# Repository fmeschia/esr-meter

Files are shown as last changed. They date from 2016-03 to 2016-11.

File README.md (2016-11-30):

ESR Meter
=========
An Arduino-based battery internal resistance meter.

Introduction
------------
This device measures the internal resistance of a battery by measuring the voltage difference at the battery terminals when a load is applied and then removed. By measuring the difference in voltage and the difference in current, the resistance is readily determined via Ohm's law.

Design goals
------------
* Measure internal resistance for batteries with voltages ranging from a 4-cell NiXX to a 4S LiPo pack
* Resistance range: 1 to 1000 mOhm
* Ability to do 4-wire measurements
* Target precision: 2% ± 1 LSB
* Ability to draw power either from the battery under test, or from a separate battery
* Powered by the Atmel ATMega328P microcontroller (so that it can be prototyped with Arduino)
* Low cost!

Design
------

This device measures the internal resistance by using Ohm's law: R = ∆V/∆I. The battery is first connected to a load, then the load is removed. The voltage at the battery teminals is measured just before removing the load, and just after the load is removed. The current drawn from the battery is also measured, almost simultaneously with the two voltage measurements.

Voltage and current measurement is performed using a 4-wire (Kelvin) technique: current is measured by a sensing resistor along the "hot" high-current path which connects the battery to the load, and voltage is sensed through two "cold" leads, that carry no current. This also allows for internal resistance measurement of the individual cells in a multi-cell battery, as long as the individual cell voltages are available at a balance tap.

One of the problems that must be solved is how to measure voltages (like the two battery under test terminals) which may exceed the ADC reference voltage. The ATMega328P microcontroller can be powered with 5.5V maximum, so if we were to do a direct measurement (battery terminals direct to ADC inputs) we would be only be able to measure a 4-cell NiXX battery... if it's not fully charged.

One possibility to overcome this problem would be to use differential analog amplifiers to bring the voltages within the measurement range. The gain and the baseline of the amplifiers could be adjusted by the micro with digital potentiometers, to adapt to different battery voltages. The drawback is the number of additional components, which influences the cost of the device.

Instead of going this route, we decided to use "AC coupling". The voltages sensed at the battery terminals are filtered through one-pole (RC) low-pass filters, so that their DC component is removed.

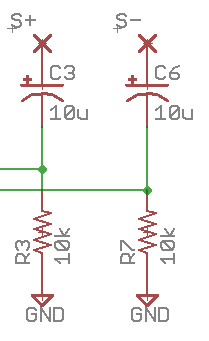
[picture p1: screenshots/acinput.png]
AC-coupled voltage sense inputs


If the time constant of the fiter is sufficiently long compared to the load-switching-to-measurement delay, we would only measure the actual change in voltage, with negligible error (compare, in the scope plot below, the yellow DC-coupled voltage at the positive battery terminal with the green AC-coupled signal: 1 ms after the load is switched off, when the measurement is taken, the AC-coupled signal is a very faithful estimate of the voltage difference at the battery terminal).

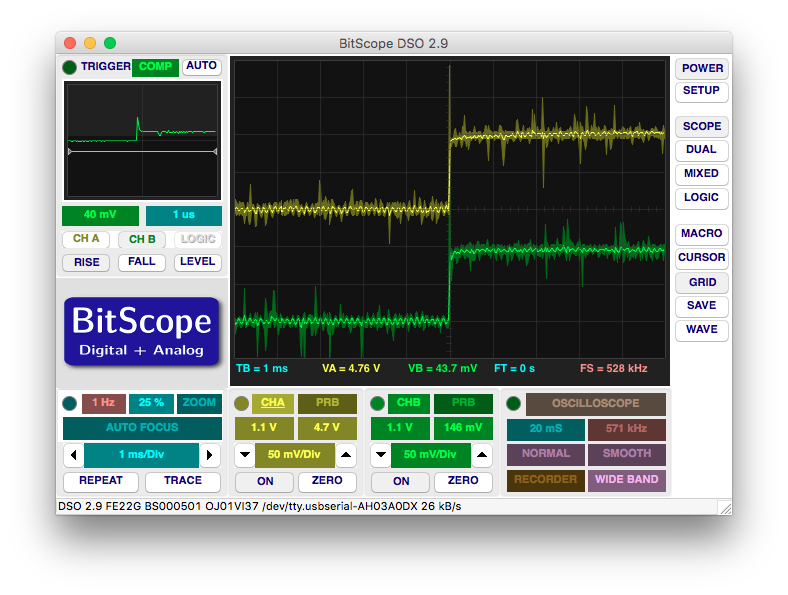
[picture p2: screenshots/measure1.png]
DC vs. AC measure of ∆V DC (yellow) vs. AC (green) measure of ∆V


In order to ensure reasonable precision with low cost, we also decided to reference the ADCs to the internal bandgap voltage reference of the micro. This means that, if we want to meet the 1 Ohm maximum range stated in the design goals, we need to draw less than about 1.1 A (we designed the prototype for 0.8 A).

Such an electronic load can be conveniently built with a LM317 regulator used as a current source. This will be the heart of the "hot" loop. Additionally, the hot loop will also include: 

*  a Schottky diode for protection against reverse polarity
*  an n-channel MOSFET used as a switch
*  a 1 Ohm, 1% precision, current sensing resistor

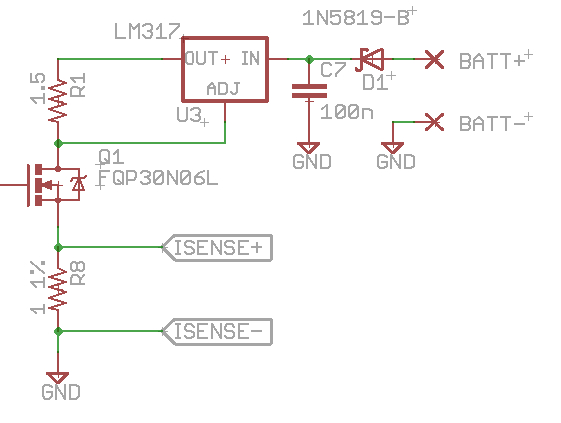
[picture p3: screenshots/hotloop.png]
Hot loop schematic


Mainly because of the LM317 dropout characteristics, the minimum voltage that needs to be applied to the hot loop if we want the design current draw is about 4 V. A lower voltage would lead to a lower current figure, as long as it is enough to correctly bias the BJTs inside the LM317 (after that, the device won't work any more). We tested the circuit with a single LiPo cell discharged to 3.5V, without any problem.

The hot loop is switched on and off by the microcontroller, which we decided to power at 3.3 V with an external clock runing at 8 MHz. The program running on the micro switches on the load for 500 ms, then switches it off for 1500 ms, before starting a new cycle. In this way, the 25% duty cycle helps in keeping the average power dissipation acceptable for a LM317 with a passive heat sink, even when sinking current from a 4S LiPo battery.

The microcontroller also drives a standard HD44780 2x16 parallel-interface LCD display module, to output the result of the internal resistance computation at the end of each 2-second measurement cycle. The measurement is automatically refreshed every 2 seconds, for as long as the unit is powered. 

Power for the circuit may come either directly from the battery under test (requires the use of a LDO regulator and a 3.3 V display module), or from a separate battery.

Making it
---------
The project includes Eagle files for both the schematics and the board. The board was designed as a 2-layer PCB with the same 80x36 mm form factor used by standard 2x16 LCD modules, and with the same mounting hole pattern, so that it can be stacked using 1" standoffs.

The Bill of Materials is also included in the project. Here are some component selection notes:

* it is important for precision to use a 1 Ohm, 1% current sensing resistor (R8 in the schematic);
* the reverse-polarity protection diode used in the hot loop (D1 in the schematic) can be replaced with a more common 1N4001 diode, but this increases the voltage drop along the hot loop and may create problems to the LM317 electronic load. If you plan to build this circuit for single-LiPo or 4S NiXX use, it is best to stick with a Schottky diode;
* the Q1 n-channel MOSFET is not critical, as long as it can reliably switch completely on with a 3.3 V gate-to-source voltage. For single-LiPo or 4 NiXX operation, a low "on" drain-to-source resistance is advisable. The FQP30N06L we suggest in the schematic has just 0.035 Ohms of forward resistance when fully "on".
* any 3.3 V low-dropout linear regulator can be used for single-battery operation. The board is designed for the footprint of a L4931. 
* the LM317 used as a current source requires a heat sink for reliable operation. The sink resistor, R1, will dissipate 1 W and must therefore be sized accordingly.

Other notes:

* the board includes two jumper headers. One, labeled "JP3", determines whether the board will be powered from the battery under test (if closed), or from an external battery (if open). In the latter case, a suitable power source must be provided at the via labeled "VCC-ALT".
* the other jumper, JP1, if closed forces the software running in the ATMega328P to show debug information (sensed voltages and currents) in addition to the resistance value.
* another header, JP2, provides an interface to the serial port of the ATMega328P. It is pin-compatible (but pay attention to the correct orientation!) with the FTDI FT232L breakout board offered by Sparkfun (https://www.sparkfun.com/products/9873). The serial port can be used to upload the software into the microcontroller if an Arduino bootloader is used.

The microcontroller must be programmed with the software found in the esr_meter directory. First the software must be compiled within the Arduino IDE, then it must be burned into the ATmega328P flash memory. There are essentially two options for that:

* if you use a microcontroller with a pre-burned Arduino bootloader, you can install the chip in the PCB, and then program it via the JP2 serial port;
* if your microcontroller doesn't have an Arduino bootleader yet, you need to use an ISP programmer (there are several options –- see https://www.arduino.cc/en/Main/Standalone for example) and burn the Arduino bootloader, then you can upload the software via the JP2 serial port.

Assembly notes:

* the LCD module is to be connected to the board with a short length of 6-lead ribbon cable. The 6 leftmost pins of JP4 go to pins 1 to 6 on the LCD module, and the 6 rightmost pins go to pins 11 to 16.
* the battery under test is to be connected to the "hot" loop through the two plated holes labeled BATT+ and BATT- on the board, of course while respecting the polarity, using two suitable wires; the holes should be able to accommodate up to AWG16. The two voltage sense leads will be soldered to the plated holes labeled S+ and S-; polarity in that case is not important, as the software can accommodate reverse polarity.
* The voltage sense leads do not necessarily need to be soldered to the battery connectors. For multiple-cell LiPo use, they can be soldered to a suitable pitch 2-pin header to sense the individual cells at the balancing connector (see picture below).

The following are some pictures of a specimen of the device:

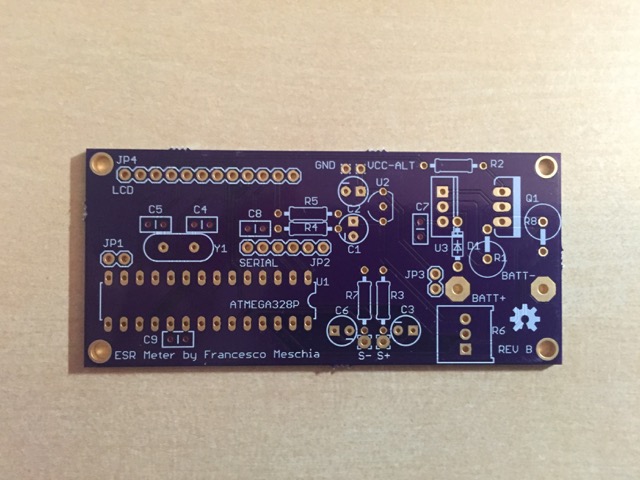
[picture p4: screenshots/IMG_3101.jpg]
The PCB The PCB for the ESR Meter

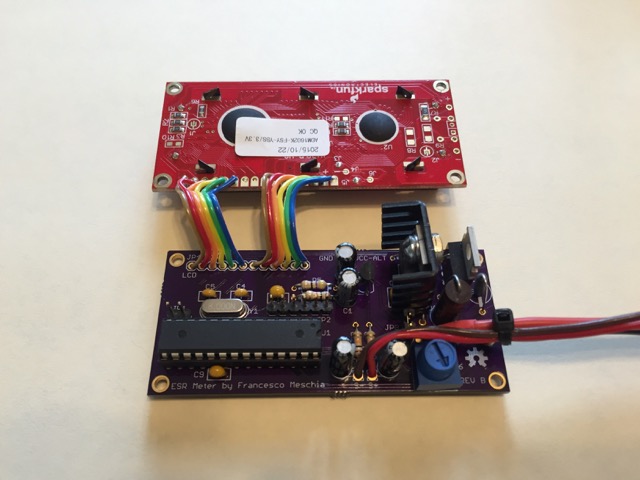
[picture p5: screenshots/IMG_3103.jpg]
Component placement overview An overview of component placement and external connections

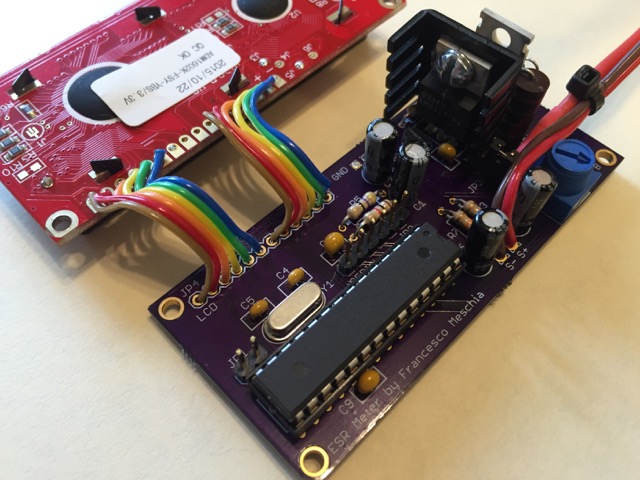
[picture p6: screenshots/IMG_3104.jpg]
Component placement detail A detail view component placement and LCD connections

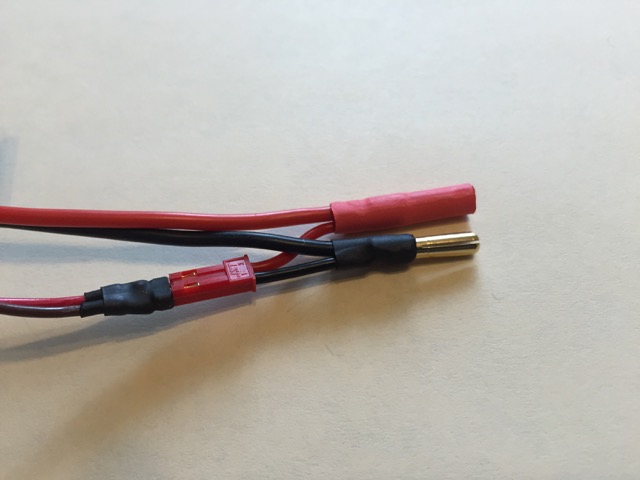
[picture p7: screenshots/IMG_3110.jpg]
Test leads with 4 mm bullet connectors The battery end of the test leads, with 4 mm bullet connectors. The voltage sense leads can be plugged into a mating connector soldered to the battery high-currentconnector, or they can be plugged into the balance connector of a LiPo battery

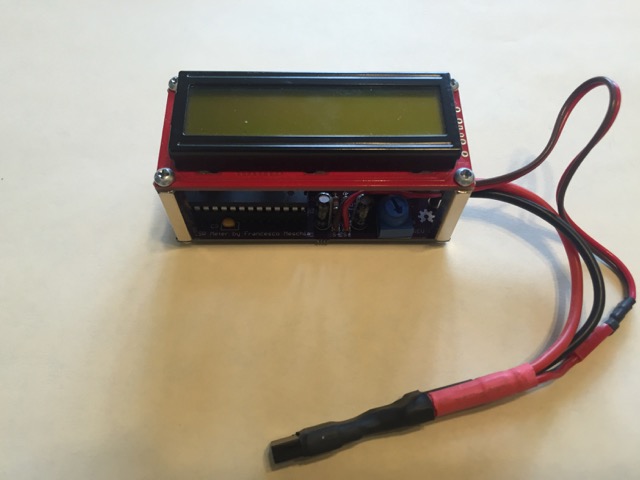
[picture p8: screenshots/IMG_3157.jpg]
Finished devide The completed device


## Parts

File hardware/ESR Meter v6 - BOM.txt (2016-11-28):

Partlist exported from esr-meter/hardware/ESR Meter v6.sch at 4/2/16 10:34 AM

Part  Value           Device                   Package              Description                                                                                                                                                                                                        PROD_ID    
C1    10u             CAP_POLPTH2              CPOL-RADIAL-10UF-25V Capacitor Polarized                                                                                                                                                                                                           
C2    10u             CAP_POLPTH2              CPOL-RADIAL-10UF-25V Capacitor Polarized                                                                                                                                                                                                           
C3    10u             CAP_POLPTH2              CPOL-RADIAL-10UF-25V Capacitor Polarized                                                                                                                                                                                                           
C4    22p             CAPEZ                    CAP-PTH-SMALLEZ      Capacitor                                                                                                                                                                                                                     
C5    22p             CAPEZ                    CAP-PTH-SMALLEZ      Capacitor                                                                                                                                                                                                                     
C6    10u             CAP_POLPTH2              CPOL-RADIAL-10UF-25V Capacitor Polarized                                                                                                                                                                                                           
C7    100n            CAPEZ                    CAP-PTH-SMALLEZ      Capacitor                                                                                                                                                                                                                     
C8    100n            CAPEZ                    CAP-PTH-SMALLEZ      Capacitor                                                                                                                                                                                                                     
C9    100n            CAPEZ                    CAP-PTH-SMALLEZ      Capacitor                                                                                                                                                                                                                     
D1    1N5819-B        1N5819-B                 DO41-7.6             1.0A SCHOTTKY BARRIER RECTIFIER                                                                                                                                                                                               
JP1                   JUMPER-2PTH              1X02                 Jumper                                                                                                                                                                                                                        
JP2                   M06SILK_FEMALE_PTH       1X06                 Header 6                                                                                                                                                                                                           CONN-08437 
JP3                   JUMPER-2PTH              1X02                 Jumper                                                                                                                                                                                                                        
Q1    FQP30N06L       MOSFET-NCHANNELFQP30N06L TO220V               Common NMOSFET Parts                                                                                                                                                                                               TRANS-10060
R1    1.5             R-US_0617/5V             0617V                RESISTOR, American symbol                                                                                                                                                                                                     
R2    2.2k            R-US_0207/10             0207/10              RESISTOR, American symbol                                                                                                                                                                                                     
R3    10k             R-US_0207/10             0207/10              RESISTOR, American symbol                                                                                                                                                                                                     
R4    1k              R-US_0207/10             0207/10              RESISTOR, American symbol                                                                                                                                                                                                     
R5    47              R-US_0207/10             0207/10              RESISTOR, American symbol                                                                                                                                                                                                     
R6    10k             TRIMPOT-PTH-KNOB         3386U                Various small potentiometers for "set-and-forget" applications                                                                                                                                                                
R7    10k             R-US_0207/10             0207/10              RESISTOR, American symbol                                                                                                                                                                                                     
R8    1 1%            R-US_0617/5V             0617V                RESISTOR, American symbol                                                                                                                                                                                                     
U1    ATMEGA328P      ATMEGA328P_PDIP          DIL28-3              uC used in the Arduino                                                                                                                                                                                                        
U2    3V3             L4931                    L4931                VOLTAGE REGULATOR                                                                                                                                                                                                             
U3    LM317           V_REG_317SINK            TO220-ADJ            Voltage Regulator                                                                                                                                                                                                             
Y1    8M              CRYSTALHC49US            HC49US               Various standard crystals. Proven footprints.

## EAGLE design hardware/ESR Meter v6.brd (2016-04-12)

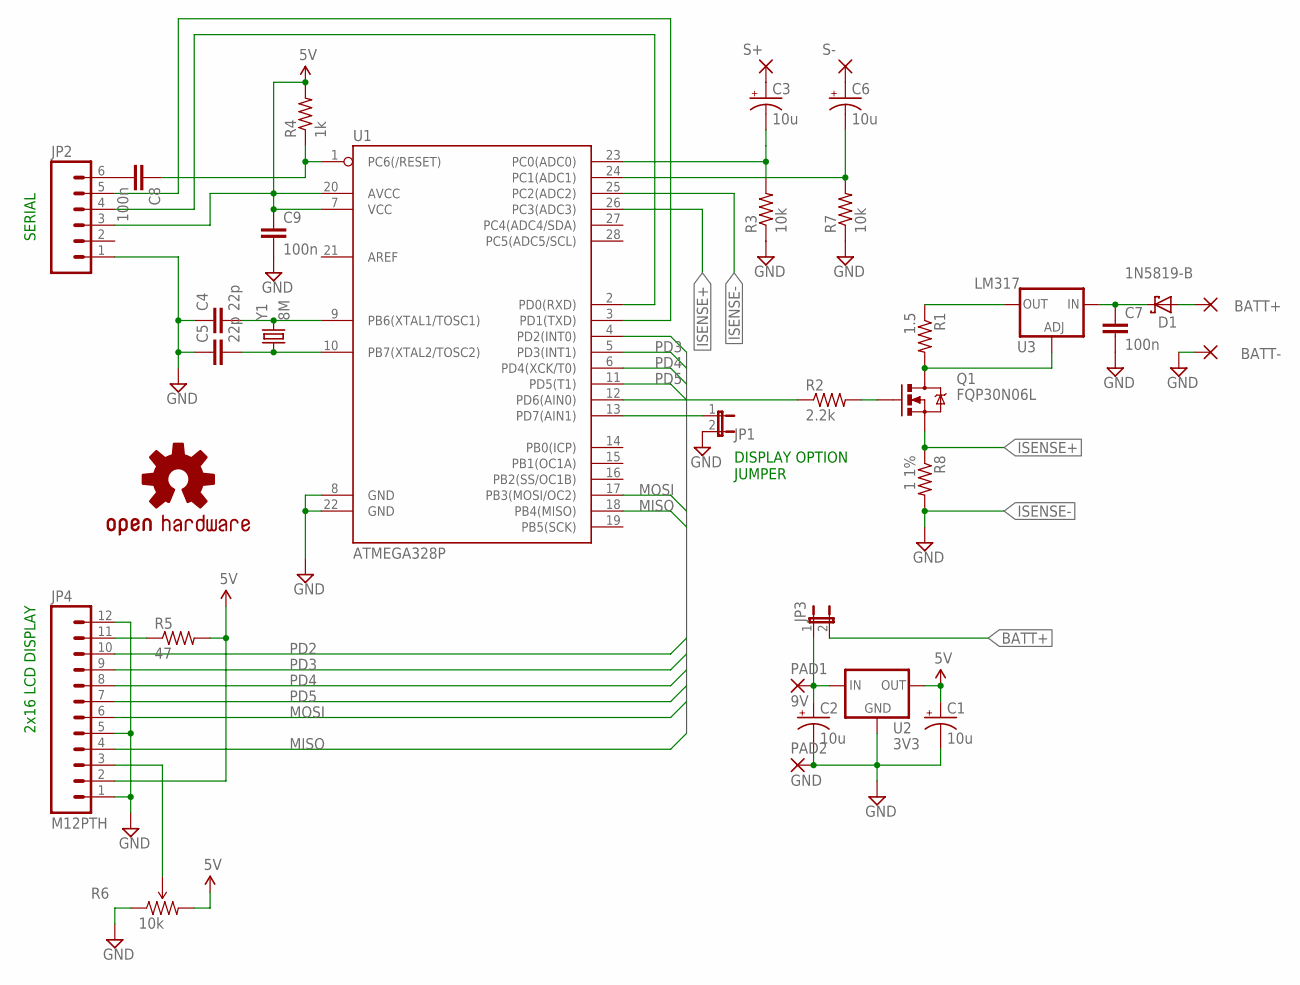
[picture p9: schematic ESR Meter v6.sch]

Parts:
BATT+: WIREPAD4,16O1,6; 4,16O1,6
BATT-: WIREPAD4,16O1,6; 4,16O1,6
C1, C2, C3, C6: 10u; CPOL-RADIAL-10UF-25V
C4, C5: 22p; CAP-PTH-SMALLEZ
C7, C8, C9: 100n; CAP-PTH-SMALLEZ
D1: 1N5819-B; DO41-7.6
JP1, JP3: JUMPER-2PTH; 1X02
JP2: M06SILK_FEMALE_PTH; 1X06
JP4: M12PTH; 1X12
LOGO1: OSHW-LOGOM; OSHW-LOGO-M
PAD1: 9V; 1,6/0,9
PAD2: GND; 1,6/0,9
Q1: FQP30N06L; TO220V
R1: 1.5; 0617V
R2: 2.2k; 0207/10
R3, R7: 10k; 0207/10
R4: 1k; 0207/10
R5: 47; 0207/10
R6: 10k; 3386U
R8: 1 1%; 0617V
S+: SENSE; 2,15/1,0
S-: SENSE; 2,15/1,0
U1: ATMEGA328P; DIL28-3
U2: 3V3; L4931
U3: LM317; TO220-ADJ
Y1: 8M; HC49US

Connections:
5V: C1.1 (+), C9.1, JP2.3, JP4.2, R4.2, R5.2, R6.3 (CW), U1.7 (VCC), U1.20 (AVCC), U2.OUT
BATT+: BATT+.1, D1.A, JP3.2
GND: BATT-.1, C1.2 (-), C2.2 (-), C4.1, C5.1, C7.2, C9.2, JP1.2, JP2.1, JP4.1, JP4.5, JP4.12, PAD2.1, R3.1, R6.1 (CCW), R7.1, R8.2, U1.8 (GND), U1.22 (GND), U2.GND
ISENSE+: Q1.3 (S), R8.1, U1.26 (PC3(ADC3))
ISENSE-: U1.25 (PC2(ADC2))
MISO: JP4.4, U1.18 (PB4(MISO))
MOSI: JP4.6, U1.17 (PB3(MOSI/OC2))
unnamed: Q1.1 (G), R2.2
unnamed: Q1.2 (D), R1.2, U3.ADJ
unnamed: R2.1, U1.12 (PD6(AIN0))
unnamed: C3.2 (-), R3.2, U1.23 (PC0(ADC0))
unnamed: C2.1 (+), JP3.1, PAD1.1, U2.IN
unnamed: C4.2, U1.9 (PB6(XTAL1/TOSC1)), Y1.2
unnamed: C5.2, U1.10 (PB7(XTAL2/TOSC2)), Y1.1
unnamed: JP4.3, R6.2 (WIPER)
unnamed: C8.2, JP2.6
unnamed: JP2.5, U1.3 (PD1(TXD))
unnamed: JP2.4, U1.2 (PD0(RXD))
unnamed: C3.1 (+), S+.1
unnamed: JP4.11, R5.1
unnamed: C6.1 (+), S-.1
unnamed: JP1.1, U1.13 (PD7(AIN1))
unnamed: C6.2 (-), R7.2, U1.24 (PC1(ADC1))
unnamed: R1.1, U3.OUT
unnamed: C7.1, D1.C, U3.IN
PD2: JP4.10, U1.4 (PD2(INT0))
PD3: JP4.9, U1.5 (PD3(INT1))
PD4: JP4.8, U1.6 (PD4(XCK/T0))
PD5: JP4.7, U1.11 (PD5(T1))
RESET: C8.1, R4.1, U1.1 (PC6(/RESET))

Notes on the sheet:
2x16 LCD DISPLAY
SERIAL
DISPLAY OPTION JUMPER

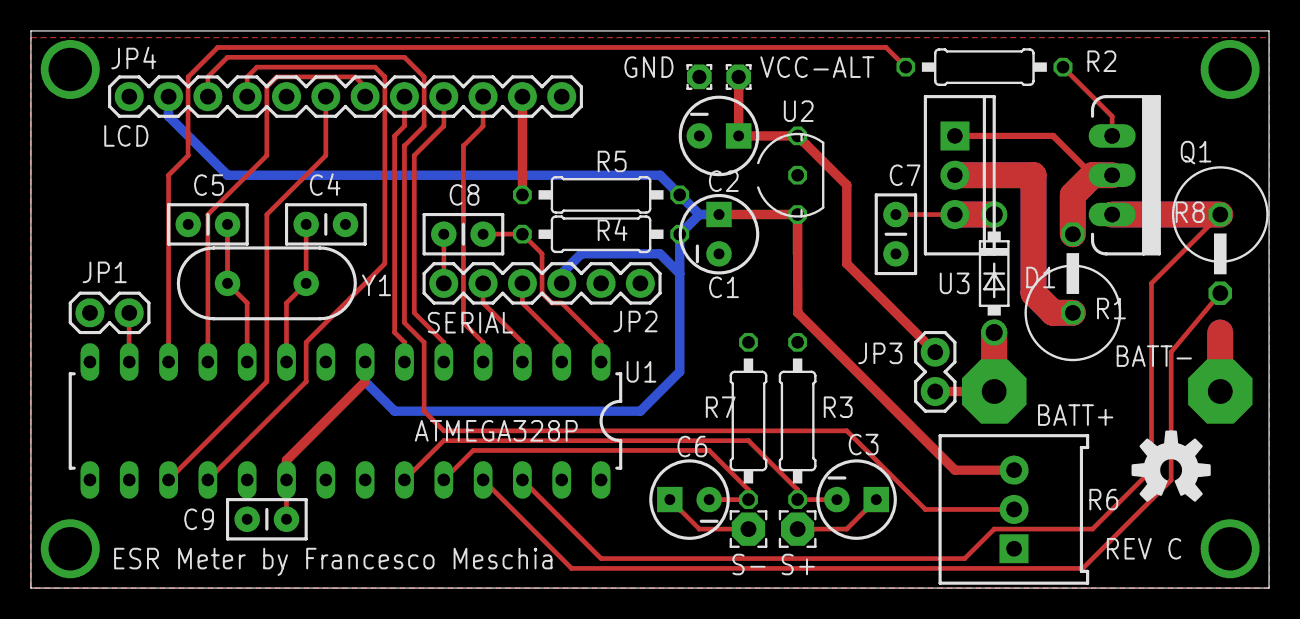
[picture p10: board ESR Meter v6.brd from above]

Board: 2 copper layers, 80.0 x 36.0 mm, 34 parts (0 on the bottom side), 29 nets.

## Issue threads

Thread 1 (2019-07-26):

R1 and R8

3xtr3m3d, 2019-07-26:
Hi

Can you please give me the links to R1 and R8 you bought for this project?

Regards

fmeschia, 2019-07-26:
I just bought those resistors from a local supplier. But you can order them from digi-key, mouser or any other online store. R8 must be 1 Ohm with 1% accuracy. R8 is not critical in Ohm value, but it must be rated for at least 1 Watt.

3xtr3m3d, 2019-07-26:
thanks for the fast response. R1 wattage is not a problem?

fmeschia, 2019-07-26:
The same current that goes through R8 also goes through R1. But R1 Ohmic value is less, so it “only” needs to be rated for at least 0.7 Watt. An example from Digi-Key is here: https://www.digikey.com/product-detail/en/ohmite/41F1R0E/41F1R0E-ND/823176

3xtr3m3d, 2019-07-26:
thanks a lot i will try that. im going to try your project as i'm testing some 18650 batteries.

thanks a lot for posting this project on github

allenchak, 2021-01-21:
Might I know which resistor is better for R1 & R8,

- 3W ±1% 1Ω
- 2W ±1% 1Ω
- 1W ±1% 1Ω
- 1W ±1% 0.1Ω
- 1W ±1% 0.68Ω

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

Moreover, in case I using ADS1115 as external ADC. Would it increase accuracy? Thank you for your reply.

fmeschia, 2021-01-21:
I would go for a 1Ohm, 1%, 1W for R8. R1 doesn’t need to be rated for 1% precision, but it should be around 1.5Ohm and 2W.
I didn’t design this circuit to use and external ADC, I think it would need to be modified rather substantially.

Closed 2023-11-10.

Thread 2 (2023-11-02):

Blank display

dickeos, 2023-11-02:
Hello,

I finally got around to building your project (thank you), everything seemed to go ok with the build, I have managed to program the board using an FTDI controller I already had lying around using Arduino IDE and the Arduino Uno board profile. It said that the upload was successful so I have no reason to think it wasn't.

I just get a blank display, it lights up but nothing on there, I have tried powering the unit externally and its the same. I didn't use the exact 16x2 display but the pin configuration was the same as the one you have used.

Any ideas what I can try to diagnose?

fmeschia, 2023-11-02:
I’d start by checking the voltage supplied to the panel. If the panel has backlighting, is it on? Does the LCD panel support 3.3V?
Next, I’d try to see if the microcontroller is working, by checking if the load is switched on and off. The measurement cycle is slow, so a multimeter should be enough.

dickeos, 2023-11-03:
Great places to start troubleshhting, can you confirm the load is on pins 25&26?

fmeschia, 2023-11-03:
Not exactly the load, but related to it. Pin 25 and 26 on the MCU read the voltages at the end of the precision 1Ohm current sense resistor, so you should see a voltage across them, from 0V to ~0.8V.

dickeos, 2023-11-09:
Turns out if was some faulty ribbon cable! It appears to work now. One last question, the 8mhz crystal, does it have to be 8mhz or will a 16mhz one suffice?

fmeschia, 2023-11-09:
8MHz is within the operating spec for the microcontroller when powered at 3.3V. 16MHz may be a bit too much for 3.3V, for that frequency 5V would be more “comfortable”.

dickeos, 2023-11-09:
Thank you so much for all of your advice, the project is great and will be very useful for me.

fmeschia, 2023-11-09:
Glad to hear that!

Closed 2023-11-10.

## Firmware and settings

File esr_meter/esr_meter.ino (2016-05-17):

/*
 
 Battery Series Resistance Meter v4
 by Francesco Meschia, January 2016
 
 */

#include <avr/sleep.h>
#include <avr/power.h>
#include <avr/wdt.h>
#include <LiquidCrystal.h>

// Digital output pin connected to the switching MOSFET gate
#define PIN_GATE 6
// Analog input pin connected to low side of voltage sense
#define PIN_VSL A1
// Analog input pin connected to high side of voltage sense
#define PIN_VSH A0
// Analog input pin connected to low side of current sense
#define PIN_IL A2
// Analog input pin connected to high side of current sense
#define PIN_IH A3
// Digital input pin connected to display option jumper 
#define PIN_OPT 7
// Internal ADC reference voltage
#define ADC_REF_VALUE 1.1
// Sample size for averaging
#define AVG_SIZE 5
// Measurement duty cycle
#define DUTY_CYCLE 0.25
// Measurement period
#define PERIOD 2000
// Delay between switching and measurement
#define MEASUREMENT_DELAY_US 1000

int state = 0;
boolean sleep_entered = false;
float v0_l, v0_h, v1_l, v1_h;
float i0_l, i0_h, i1_l, i1_h;

LiquidCrystal lcd(12, 11, 5, 4, 3, 2);

void setup() {
  analogReference(INTERNAL);
  pinMode(PIN_VSL, INPUT);
  pinMode(PIN_VSH, INPUT);
  pinMode(PIN_IL, INPUT);
  pinMode(PIN_IH, INPUT);
  pinMode(PIN_OPT, INPUT_PULLUP);
  pinMode(PIN_GATE, OUTPUT);
  digitalWrite(PIN_GATE, HIGH);
  lcd.begin(16, 2);
  lcd.print("ESR Meter v0.4");
  Serial.begin(9600);
  Serial.println("ESR Meter v0.4 ready");
  delay(1000);
  for (int i=0; i<100; i++) {
    analogRead(PIN_VSL); 
    analogRead(PIN_VSH); 
    analogRead(PIN_IL); 
    analogRead(PIN_IH);
  }
  //configure_wdt();
}

inline void configure_wdt() {
  cli();
  wdt_reset();
  MCUSR &= ~_BV(WDRF);
  WDTCSR |= (_BV(WDCE) | _BV(WDE));   // Enable the WD Change Bit
  WDTCSR =   _BV(WDIE) |              // Enable WDT Interrupt
  _BV(WDP2) | _BV(WDP1) | _BV(WDP0);   // Set Timeout to ~1 seconds
  sei();
}

ISR(WDT_vect)
{
  /* Check if we are in sleep mode or it is a genuine WDR. */
  if(sleep_entered == false)
  {
    /* The app has locked up, force a WDR. */
    wdt_enable(WDTO_15MS);
    while(1);
  }
  else
  {
    wdt_reset();
    /* Service the timer if necessary. */
    sleep_entered = false;
    sleep_disable();

    /* Inline function so OK to call from here. */
    configure_wdt();
  }
}

void loop() {
  // when loop() is entered, MOSFET gate is high and load is on
  // wait until duty cycle is expired
  delay(PERIOD * DUTY_CYCLE);
  // measure current and voltages at the sense resistor and high-pass voltage sense lines
  // (duty cycle needs to be set so that voltages at the output of the high-pass sense lines
  // have reached zero at this time, as ADC can't mesure negative voltages)
  v0_h = 0.0; 
  v0_l = 0.0; 
  i0_l = 0.0;
  i0_h = 0.0;
  for (int i=0; i<AVG_SIZE; i++) {
    v0_l += analogRead(PIN_VSL);
    v0_h += analogRead(PIN_VSH);
    i0_l += analogRead(PIN_IL);
    i0_h += analogRead(PIN_IH);
  }
  v0_h /= AVG_SIZE;
  v0_h *= 1000.0 * ADC_REF_VALUE / 1024.0;
  v0_l /= AVG_SIZE; 
  v0_l *= 1000.0 * ADC_REF_VALUE / 1024.0;
  i0_l /= AVG_SIZE;
  i0_l *= ADC_REF_VALUE / 1024.0;
  i0_h /= AVG_SIZE;
  i0_h *= ADC_REF_VALUE / 1024.0;

  // set MOSFET gate to low (disconnect load)
  digitalWrite(PIN_GATE, LOW);
  /*
  lcd.clear();
   lcd.setCursor(0,0);
   lcd.print("LOW");
   */
  // delay just enough to suppress ringing
  delayMicroseconds(MEASUREMENT_DELAY_US);

  // measure current and voltages at the sense resistor and high-pass voltage sense lines
  v1_l = 0.0;
  v1_h = 0.0;
  i1_l = 0.0;
  i1_h = 0.0;
  for (int i=0; i<AVG_SIZE; i++) {
    v1_l += analogRead(PIN_VSL);
    v1_h += analogRead(PIN_VSH);
    i1_l += analogRead(PIN_IL);
    i1_h += analogRead(PIN_IH);
  }
  v1_h /= AVG_SIZE;
  v1_h *= 1000.0 * ADC_REF_VALUE / 1024.0;
  v1_l /= AVG_SIZE; 
  v1_l *= 1000.0 * ADC_REF_VALUE / 1024.0; 
  i1_l /= AVG_SIZE;
  i1_l *= ADC_REF_VALUE / 1024.0;
  i1_h /= AVG_SIZE;
  i1_h *= ADC_REF_VALUE / 1024.0;

  /*
  lcd.clear();
   lcd.setCursor(0,0);
   lcd.print("HIGH");
   */

  // compute resistance using the dV/dI method. Use absolute values to cope with
  // the possibility of reverse polarity in the sense line connections
  int res = fabs((v1_h - v1_l) - (v0_h - v0_l)) / fabs((i1_h - i1_l) - (i0_h - i0_l));

  // The display option pin is used to show raw measurements (when shorted to ground)
  if (digitalRead(PIN_OPT) == LOW) {
    if (state == 0) {
      lcd.clear();
      lcd.setCursor(0,0);
      lcd.print("V0 = ");
      lcd.print(v0_l,0);
      lcd.setCursor(10,0);
      lcd.print(v0_h,0);
      lcd.setCursor(14,0);
      lcd.print("mV");
      lcd.setCursor(0,1);
      lcd.print("V1 = ");
      lcd.print(v1_l,0);
      lcd.setCursor(10,1);
      lcd.print(v1_h,0);
      lcd.setCursor(14,1);
      lcd.print("mV");
    } 
    else if (state == 1) {
      lcd.clear();
      lcd.setCursor(0,0);
      lcd.print("I0 = ");
      lcd.print(1000*i0_l,0);
      lcd.setCursor(10,0);
      lcd.print(1000*i0_h,0);
      lcd.setCursor(14,0);
      lcd.print("mA");
      lcd.setCursor(0,1);
      lcd.print("I1 = ");
      lcd.print(1000*i1_l,0);
      lcd.setCursor(10,1);
      lcd.print(1000*i1_h,0);
      lcd.setCursor(14,1);
      lcd.print("mA");
    } 
    else if (state == 2) {
      if (i0_h > 0.01) {
        lcd.clear();
        lcd.setCursor(0,0);
        lcd.print("Rs = ");
        lcd.print(res);
        lcd.print(" m\364");
      } 
    }
    state++;
    state %= (i0_h > 0.01 ? 3 : 2);
    //flip = !flip;
  } 
  else {
    state = 0;
    lcd.clear();
    lcd.setCursor(0,0);
    if (i0_h > 0.01) {
      lcd.print("Rs = ");
      lcd.print(res);
      lcd.print(" m\364");
    } 
    else {
      lcd.print("Connect Battery");
    } 
  }
  delay(PERIOD * (1-DUTY_CYCLE));

  /*
  set_sleep_mode(SLEEP_MODE_PWR_iDOWN);
   sleep_enable();
   sleep_entered = true;
   sleep_mode();
   sleep_disable();
   power_all_enable();
   */

  digitalWrite(PIN_GATE, HIGH);
}

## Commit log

2016-02-15 Renamed files to conform to Arduino IDE needs
2016-02-15 Added Eagle hardware files
    [ESR Meter v6.brd, ESR Meter v6.sch]
2016-02-15 Update library used for L4931
    [ESR Meter v6.brd, ESR Meter v6.sch]
2016-03-29 Rewrote README.md
    [ESR Meter v6.brd, ESR Meter v6.sch]
2016-03-31 Edited README
    [ESR Meter v6.brd, ESR Meter v6.sch]
2016-04-05 Added BOM. Minor changes to schematics and board.
    [ESR Meter v6.brd, ESR Meter v6.sch]
2016-04-11 Board revision C, with additional clearance for supply and "HV" (battery) traces
    [ESR Meter v6.brd, ESR Meter v6.sch]
2016-04-12 Further tweaks with trace clearance
    [ESR Meter v6.brd, ESR Meter v6.sch]

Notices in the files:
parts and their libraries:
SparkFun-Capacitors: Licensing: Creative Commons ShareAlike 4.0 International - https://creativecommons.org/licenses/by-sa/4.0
